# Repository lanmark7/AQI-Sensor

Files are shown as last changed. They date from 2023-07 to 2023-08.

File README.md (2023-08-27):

# Air Quality Sensor

The purpose of this project is to create a stand-alone sensor device for indoor capture of air quality metrics that are displayed on the eInk screen on the device as well as report measurements to Home Assistant.  This project was inspired by the various forest fires causing poor AQI as well as local neighbors firepits that can spike indoor air quality.

# Device Details

Sensirion Sen55 Sensor:  ([Datasheet](https://sensirion.com/media/documents/6791EFA0/62A1F68F/Sensirion_Datasheet_Environmental_Node_SEN5x.pdf))
- Temperature
- Humidity
- PM1, PM2.5, PM4, PM10
- VOC
- NOx

NeoPixel LED (WS2812b):
- LED for showing alert status

# Device Design

The case design is built around a small-ish form factor that allows the eInk display to be centered even though the connector placement and the fact it is a side mounted connector makes for a wider case.  The extra width does allow for some decent component placement like a battery pack, processor and core sensor.

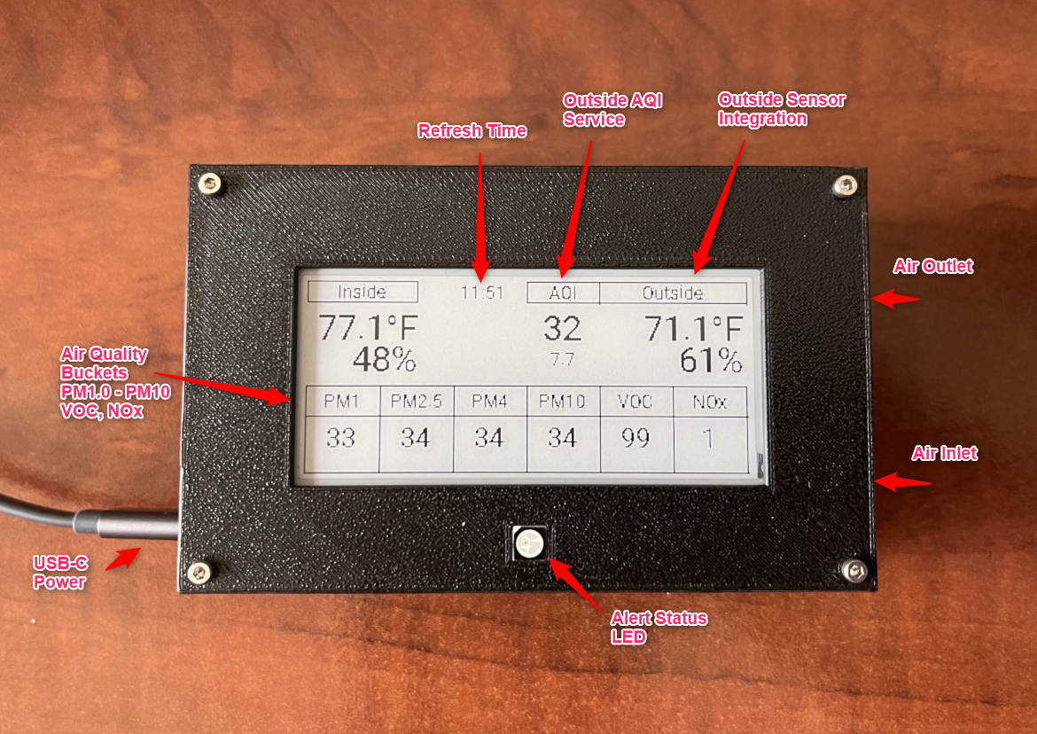
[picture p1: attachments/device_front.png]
device_front


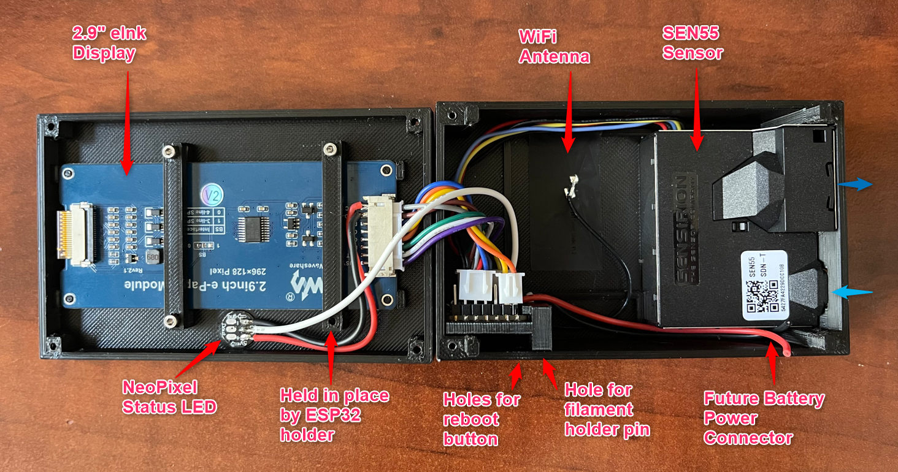
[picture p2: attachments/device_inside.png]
device_inside


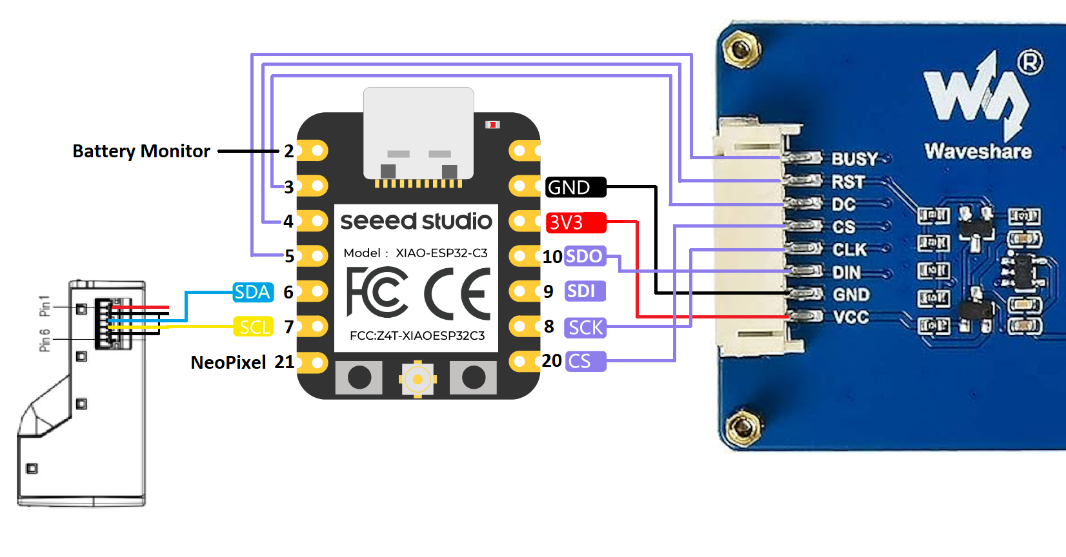
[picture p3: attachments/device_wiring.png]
device_wiring


# Outside AQI Sensing

Leveraging a commercial / government sensor for outside sensing of AQI on PM2.5 is the ideal configuration.  AirNow.gov has a API which Home Assistant has a integration created to pull in the sensor data.

You must first get a API key here:
https://docs.airnowapi.org/

# Battery Monitoring

I started out attempting to make this sensor battery powered in addition to USB powered, however I just can't get consistent results yet and so the battery monitoring component of this project has been put on hold in favor of a always plugged in design approach.

# Case Design

## Latest Design

After a number of 3D printing and fitting components this design.  This version is the 5th version of the case front and 3rd version of the back.  The back I think needs another revision to give a little bit more room for the SEN55 sensor since it is overly tight.

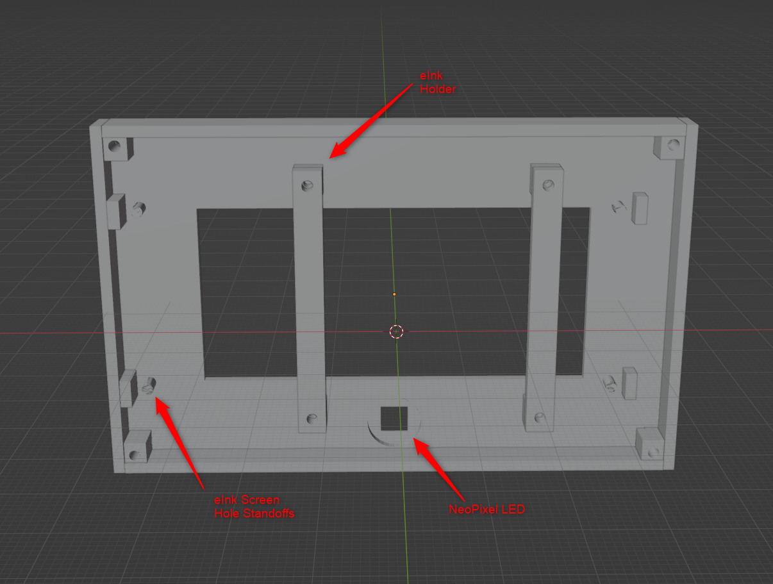
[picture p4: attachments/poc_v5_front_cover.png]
poc_v5_front


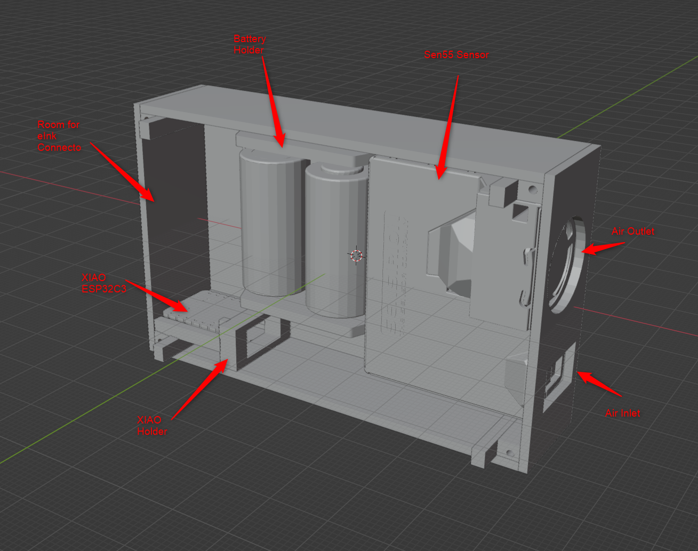
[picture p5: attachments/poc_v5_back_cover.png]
poc_v5_back


## First Proof of Concept (aka: v1)

Original first attempt at fitting in the components and getting a feel for size and functionality.

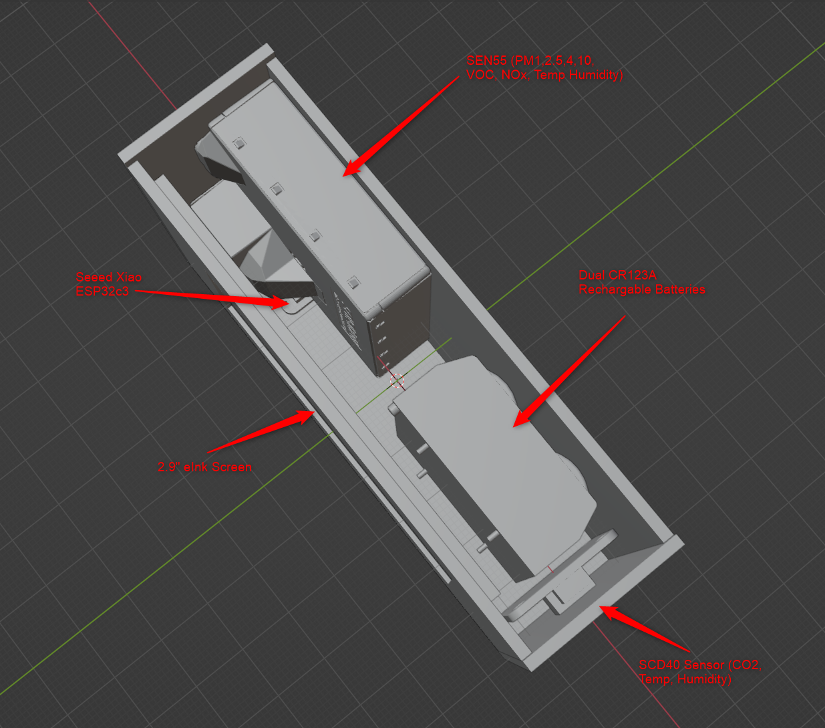
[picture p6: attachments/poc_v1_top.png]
poc_v1_top


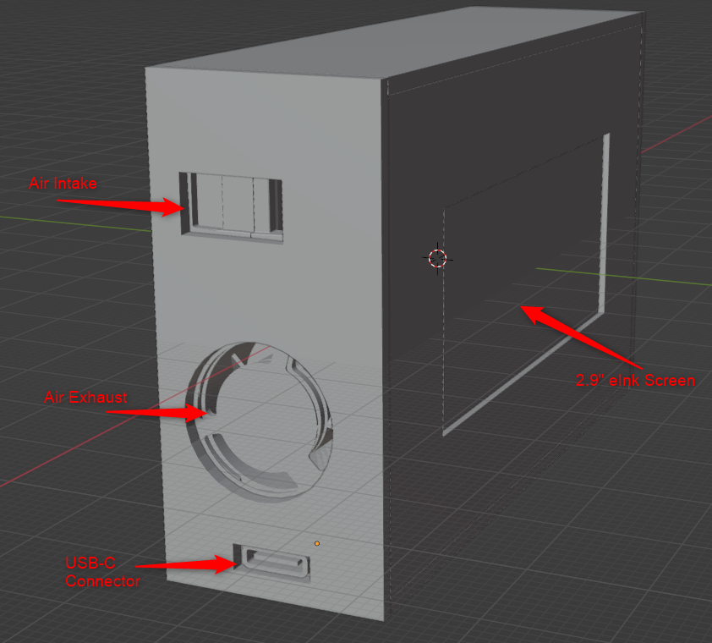
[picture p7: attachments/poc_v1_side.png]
poc_v1_side


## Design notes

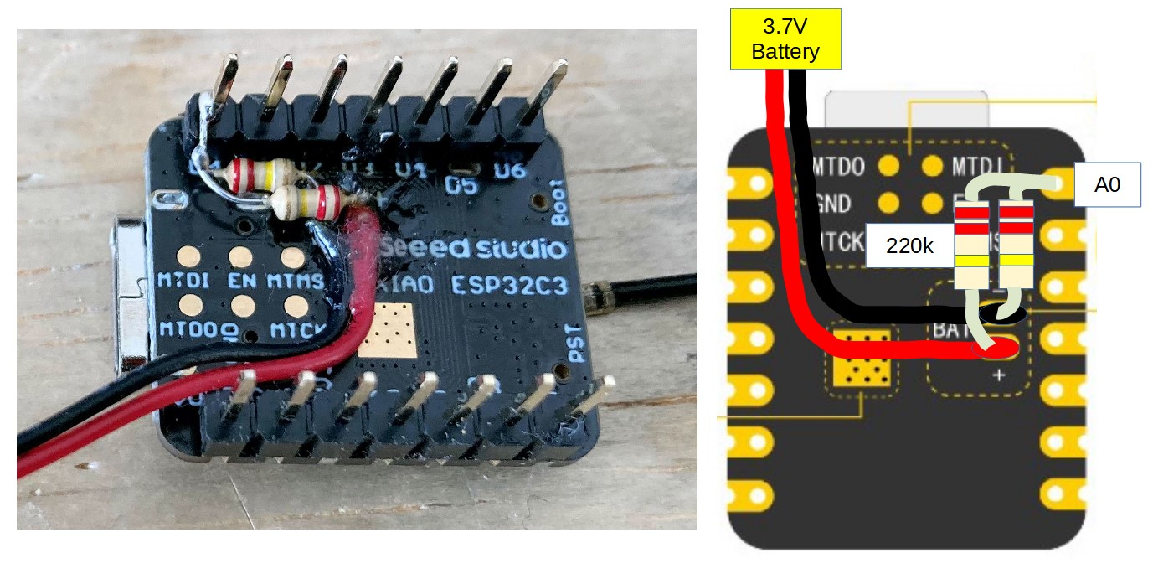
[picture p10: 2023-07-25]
equipment/Seeeduino-XIAO-Battery-Monitor.jpg

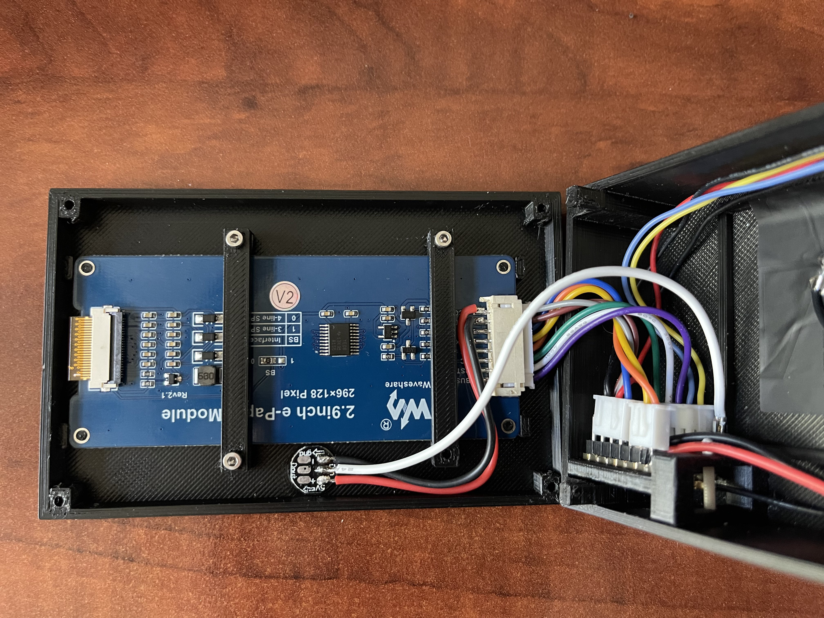
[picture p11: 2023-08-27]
attachments/devices_inside_2.jpg

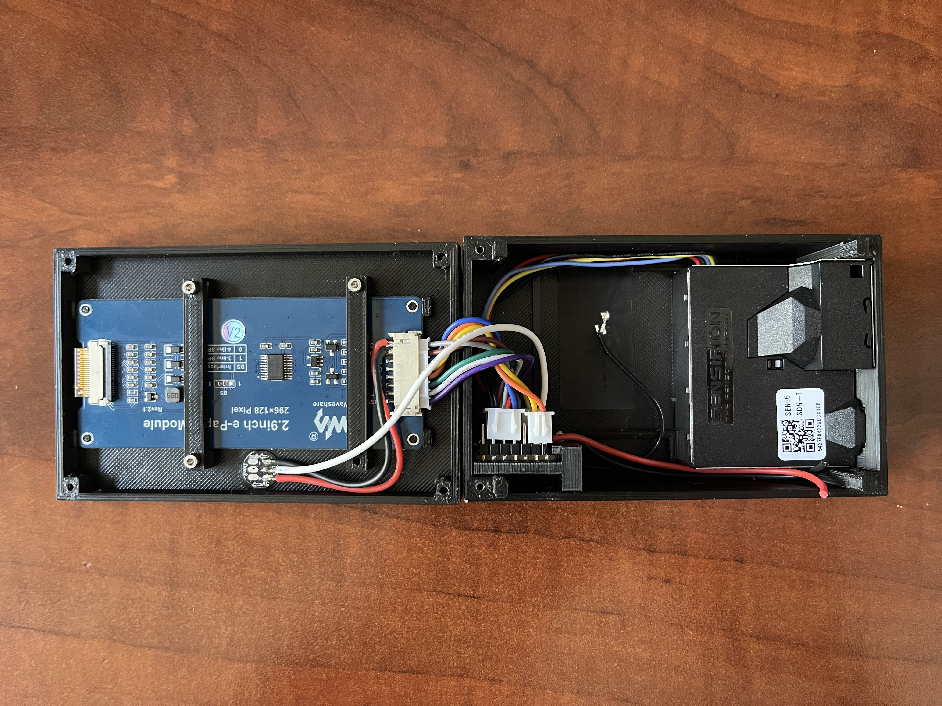
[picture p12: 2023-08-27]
attachments/device_inside.jpg

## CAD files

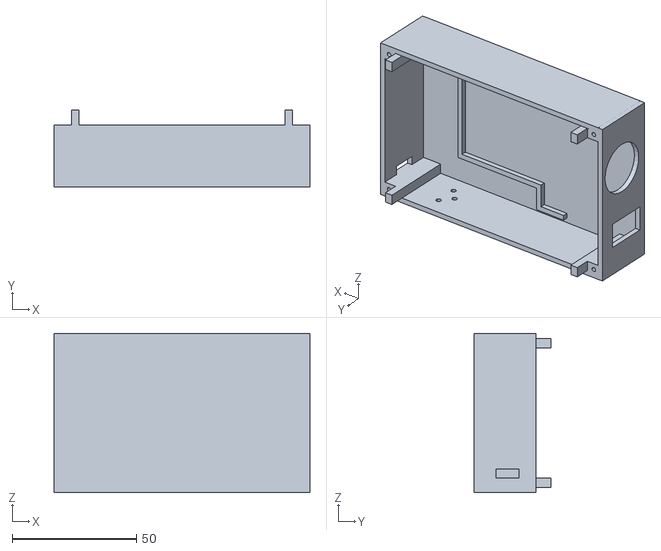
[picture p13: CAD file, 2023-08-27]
case-design/AqiSensor_Back_v3.stl
103.0 x 31.0 x 64.0

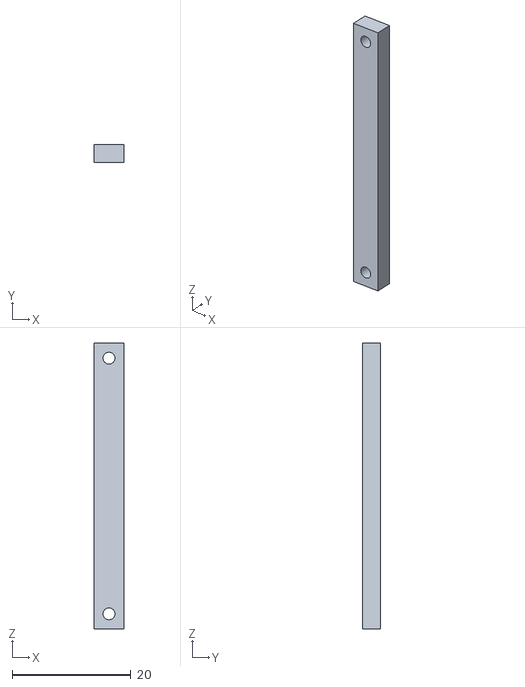
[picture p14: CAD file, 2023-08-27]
case-design/AqiSensor_Front_v4_Plate.stl
5.00 x 3.00 x 48.1

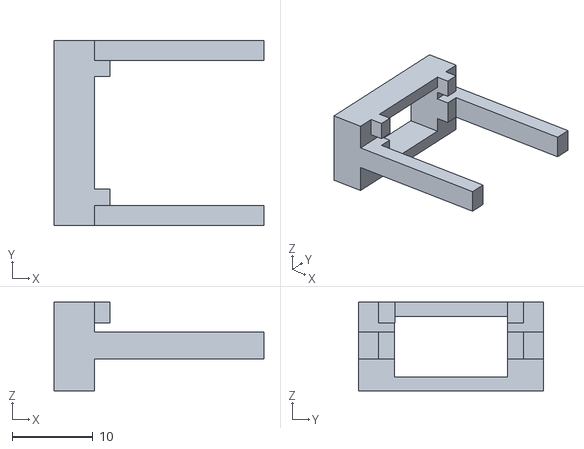
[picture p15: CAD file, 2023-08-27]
case-design/ESPHolder.stl
26.1 x 23.0 x 11.0

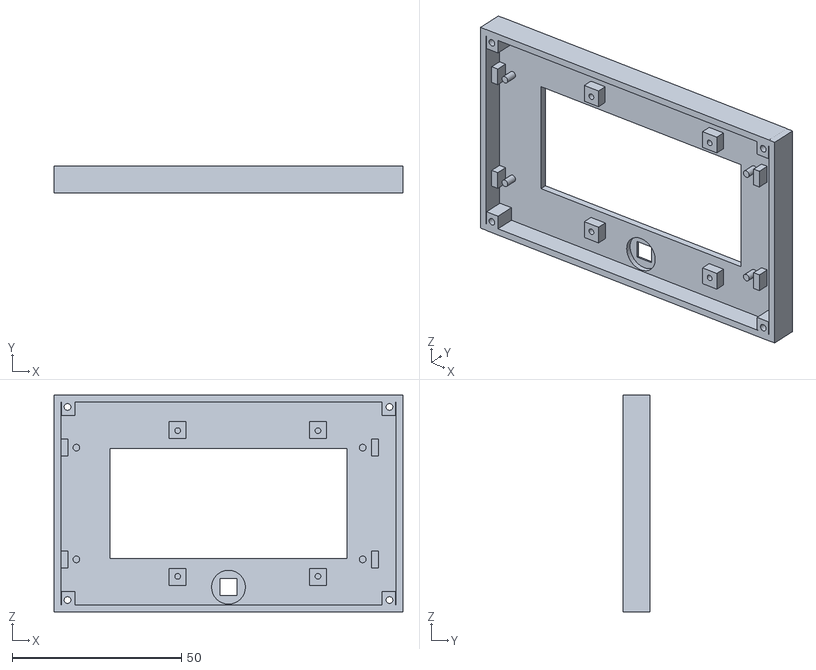
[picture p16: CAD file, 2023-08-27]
case-design/AqiSensor_Front_v5.stl
103.0 x 8.00 x 64.0

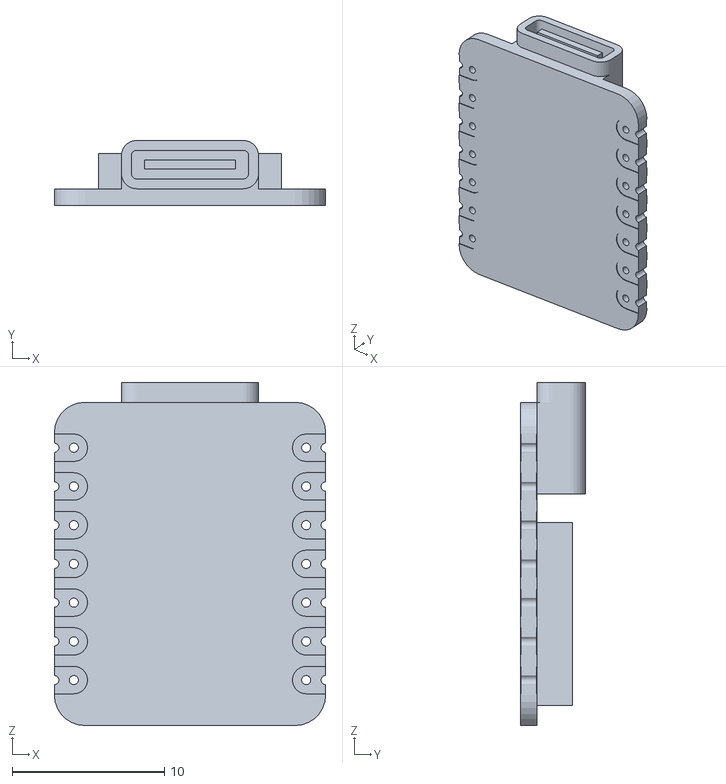
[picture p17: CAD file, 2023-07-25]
case-design/Seeeduino Xiao.stl
17.8 x 4.27 x 22.5

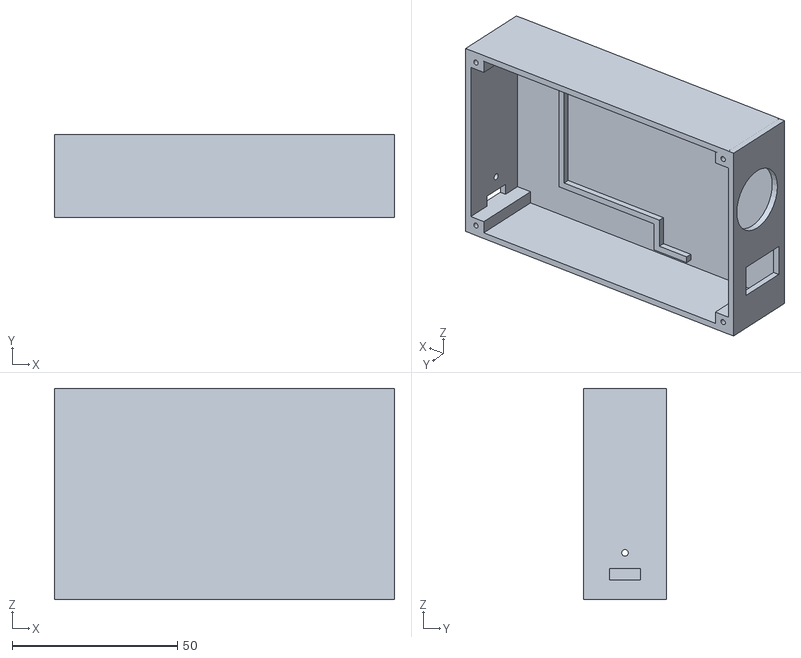
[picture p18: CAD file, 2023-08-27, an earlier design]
case-design/AqiSensor_Back_v2.stl
103.0 x 25.0 x 64.0

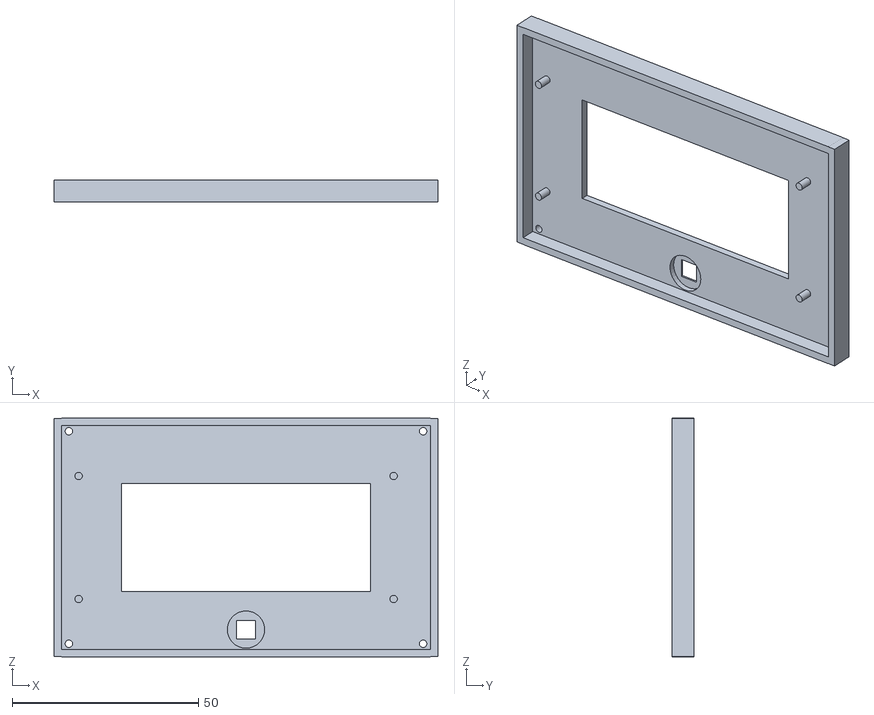
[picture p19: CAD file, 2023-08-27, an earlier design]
case-design/AqiSensor_Front_v3.stl
103.0 x 6.00 x 64.0

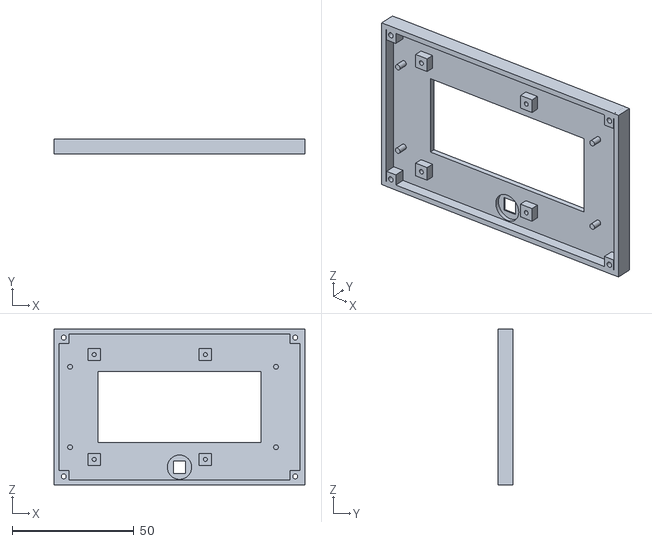
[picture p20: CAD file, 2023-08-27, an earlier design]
case-design/AqiSensor_Front_v4.stl
103.0 x 6.00 x 64.0

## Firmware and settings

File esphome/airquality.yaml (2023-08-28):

substitutions:
  device_id: airquality
  device_key: "xxxxxxxxxxxxxxxxxxxxxxxxxxxxxxxxxxxxx=="
  device_password: "xxxxxxxxxxxxxxxxxxxxxxxxxxxxxxxx"

packages:
  xiao: !include xiao-esp32c3-common.yml

spi:  
  mosi_pin: 10  # DSO
  miso_pin: 9   # DSI
  clk_pin: 8    # SCK

time:
  - platform: homeassistant
    id: homeassistant_time
  
light:
  - platform: neopixelbus
    id: ${device_id}_status_led
    name: ${device_id}.status_led
    type: GRB
    variant: WS2811
    pin: 21
    num_leds: 1

api:
  services:
    - service: airquality_fan_autoclean
      then:
        - sen5x.start_fan_autoclean: sen55

globals:
  - id: current_status
    type: int
    restore_value: no
    initial_value: '0'

sensor:
  - platform: homeassistant
    id: airnow_pm2_5
    entity_id: sensor.airnow_pm2_5

  - platform: homeassistant
    id: airnow_aqi
    entity_id: sensor.airnow_aqi

  - platform: homeassistant
    id: aqi_outside_temperature
    entity_id: sensor.kdsm_temperature

  - platform: homeassistant
    id: aqi_outside_humidity
    entity_id: sensor.kdsm_relative_humidity

  - platform: sen5x
    id: sen55
    acceleration_mode: low
    store_baseline: true
    address: 0x69
    update_interval: 15s
    temperature:
      id: ${device_id}_temp
      name: ${device_id}.temp
      accuracy_decimals: 1
      filters:
        - lambda: return x * (9.0/5.0) + 32.0;
      unit_of_measurement: "F"
    humidity:
      id: ${device_id}_humidity
      name: ${device_id}.humidity
      accuracy_decimals: 0
      unit_of_measurement: "%"
    pm_1_0:
      id: ${device_id}_pm1
      name: ${device_id}.pm1
      accuracy_decimals: 1
      unit_of_measurement: "ug/m3"
    pm_2_5:
      id: ${device_id}_pm25
      name: ${device_id}.pm25
      accuracy_decimals: 1
      unit_of_measurement: "ug/m3"
    pm_4_0:
      id: ${device_id}_pm4
      name: ${device_id}.pm4
      accuracy_decimals: 1
      unit_of_measurement: "ug/m3"
    pm_10_0:
      id: ${device_id}_pm10
      name: ${device_id}.pm10
      accuracy_decimals: 1
      unit_of_measurement: "ug/m3"    
    voc:
      id: ${device_id}_voc
      name: ${device_id}.voc
      # algorithm_tuning:
      #   index_offset: 100
      #   learning_time_offset_hours: 12
      #   learning_time_gain_hours: 12
      #   gating_max_duration_minutes: 180
      #   std_initial: 50
      #   gain_factor: 230
    nox:
      id: ${device_id}_nox
      name: ${device_id}.nox
      # algorithm_tuning:
      #   index_offset: 100
      #   learning_time_offset_hours: 12
      #   learning_time_gain_hours: 12
      #   gating_max_duration_minutes: 180
      #   std_initial: 50
      #   gain_factor: 230
    temperature_compensation:
      offset: 0
      normalized_offset_slope: 0
      time_constant: 0

# https://github.com/DeastinY/esphome-waveshare-e-paper-dashboard
font:
  - file:
      type: gfonts
      family: Roboto
    id: font12
    size: 12

  - file:
      type: gfonts
      family: Roboto
    id: font18
    size: 18

  - file:
      type: gfonts
      family: Roboto
    id: font24
    size: 24

display:
  - platform: waveshare_epaper
    id: ${device_id}_waveshare_2_9    
    busy_pin: 5
    reset_pin: 4
    dc_pin: 3
    cs_pin: 20    
    model: 2.90inv2
    rotation: 90
    full_update_every: 1
    update_interval: 30s
    reset_duration: 2ms
    lambda: |-
      #define Color1 1.0, 0.5, 0.0
      #define Color2 1.0, 0.5, 0.0
      #define Color3 1.0, 1.0, 0.0
      #define Color4 1.0, 0.0, 0.0

      it.rectangle(0, 0, 74, 15);
      it.print(20, 0, id(font12), "Inside");
      if (id(${device_id}_temp).has_state()) {
        it.printf(74, 17, id(font24), TextAlign::TOP_RIGHT , "%.1f°F", id(${device_id}_temp).state);
      }
      if (id(${device_id}_humidity).has_state()) {
        it.printf(74, 38, id(font24), TextAlign::TOP_RIGHT , "%.0f%%", id(${device_id}_humidity).state);
      }
      
      /* TIME */
      it.strftime(117, 0, id(font12), TextAlign::TOP_CENTER, "%H:%M", id(homeassistant_time).now());

      it.printf(171, 0, id(font12), TextAlign::TOP_CENTER , "AQI");
      if (id(airnow_aqi).has_state()) {
        it.printf(171, 17, id(font24), TextAlign::TOP_CENTER , "%.0f", id(airnow_aqi).state);
      }
      if (id(airnow_pm2_5).has_state()) {
        it.printf(171, 45, id(font12), TextAlign::TOP_CENTER , "%.1f", id(airnow_pm2_5).state);
      }
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

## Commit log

2023-07-25 Initial Checkin
    [Seeeduino-XIAO.stl]
2023-08-27 Updated project status
    [AqiSensor_Back_v2.stl, AqiSensor_Back_v3.stl, AqiSensor_Front_v3.stl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]
2023-08-27 Fix for esphome script
    [airquality.yaml]
2023-08-27 updated readme documentation
    [AqiSensor_TestFront.stl, AqiSensor_TestFrontv2.stl]
2023-08-28 adding status LED logic to esphome yml file
